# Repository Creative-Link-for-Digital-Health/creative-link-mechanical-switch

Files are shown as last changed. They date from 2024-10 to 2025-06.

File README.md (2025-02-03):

# Creative Link Mechanical Switch (CLMS)
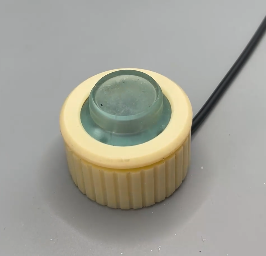
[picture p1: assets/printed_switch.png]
Printed
.
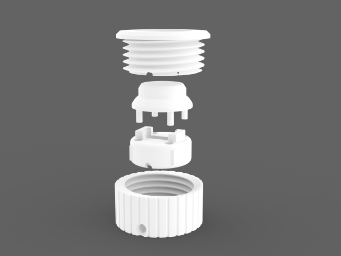
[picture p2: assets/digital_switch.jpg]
Digital
.
## Setup ##
*Hyperlink/Button to Youtube Tutorial*
1) Thread wire through hole of the 'mount'
2) Solder switch component to wire
3) Ensure switch component is flush with the top of the 'mount'
4) Firmly press the cord into the bottom inlaid portion of the 'mount'
5) Align the pegs of 'button' with the holes of the 'mount' *They will only perfectly fit in one orientation, if correct a click will be heard*
6) Align the pointed side pegs of the mount with the inside of the 'top screw'. Slide the 'button' and 'mount' through the bottom of the 'top screw' *Align the exit hole of the 'mount' and the 'top screw'*
7) Thread the end of the wire through the top of the 'bottom screw'. Screw together the 'top' and 'bottom' screw
## Citation
Use the following to cite Creative Link For Digital Health Two Part Switch:

- Smith H, Cooley Hidecker M J, Kitzman P,
  **Creative Link**, 2024-,
  https://github.com/Creative-Link-for-Digital-Health/two-part-switch/ [Online; accessed ```<year>-<month>-<day>```].

```latex
@Misc{,
  author = {Hannah Smith and Mary Jo Cooley Hidecker and Patrick Kitzman},
  title = {Creative Link for Digital Health: Mechanical Switch},
  year = {2024--},
  url = "https://github.com/Creative-Link-for-Digital-Health/two-part-switch/",
  note = {[Online; accessed <today>]}
}
```
This project was developed with support from the [University of Kentucky Office of the Vice President for Research](https://www.research.uky.edu/vice-president-research) Emerging Themes for Research Program – [Creative Link for Advancing Digital Health](https://creative.ai.uky.edu/).

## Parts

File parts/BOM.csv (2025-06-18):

Bill of Materials
Item: | Amount: | Source: | Link:
Tactile Tact Push Button | 1 | Octopart | https://octopart.com/search?q=SS-3GP
Open End TRS | 1 | Amazon | https://www.amazon.com/Fancasee-Replacement-Connector-Headphone-Earphone/dp/B082VVWND3
Switch_Bottom_Screw | 1 | Print | https://github.com/Creative-Link-for-Digital-Health/creative-link-mechanical-switch/tree/main/parts
Switch_Top_Screw | 1 | Print | https://github.com/Creative-Link-for-Digital-Health/creative-link-mechanical-switch/tree/main/parts
Switch_Button | 1 | Print | https://github.com/Creative-Link-for-Digital-Health/creative-link-mechanical-switch/tree/main/parts
Switch_Mount | 1 | Print | https://github.com/Creative-Link-for-Digital-Health/creative-link-mechanical-switch/tree/main/parts

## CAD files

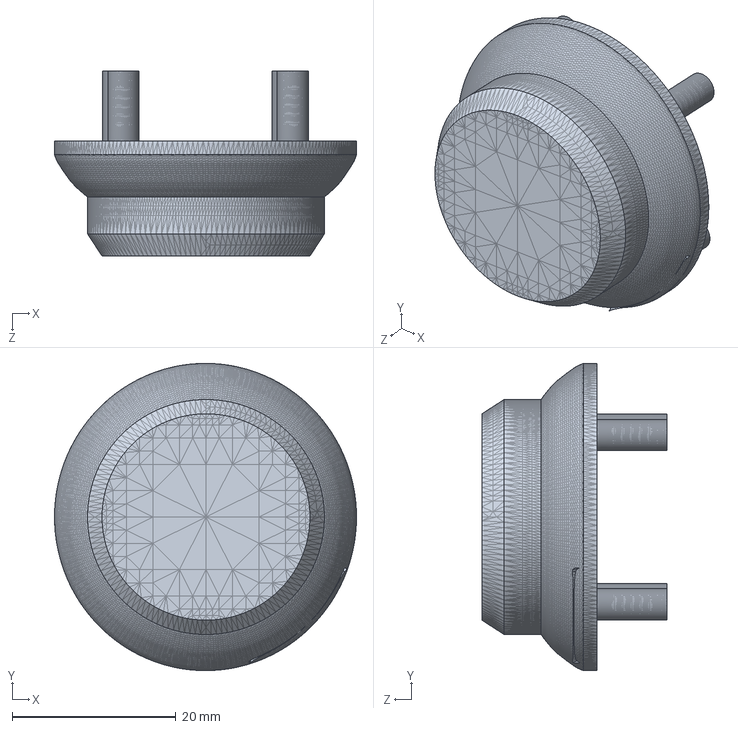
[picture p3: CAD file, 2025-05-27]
parts/switch_button_v1_sla_final_solidworks.SLDPRT
36.9 x 37.5 x 22.6 mm

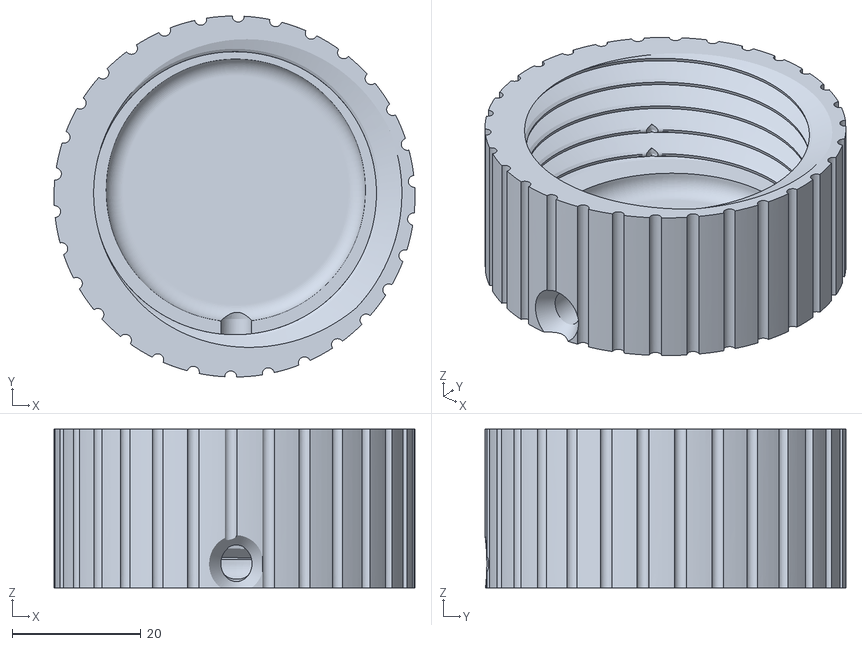
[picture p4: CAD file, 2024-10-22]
parts/switch_bottom_screw_v1_sla_final.stl
56.1 x 56.1 x 24.7

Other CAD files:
parts/switch_button_v1_sla_final.stl

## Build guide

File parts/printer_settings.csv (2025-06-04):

Parameters | Values
Material | PLA
Layer Height | 0.20
Infill Percentage | 20
Infill Pattern | Gyroid

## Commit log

2024-11-05 moved BOM
    [BOM.csv]
2024-11-10 Rename switch bottom screw_V1_sla_final.stl to switch_bottom_screw_V1_sla_final.stl
    [switch bottom screw_V1_sla_final.stl, switch_bottom_screw_V1_sla_final.stl]
2024-11-10 Rename switch_bottom screw_V1_sla_final.stl to switch_bottom_screw_v1_sla_final.stl
    [switch_bottom screw_V1_sla_final.stl, switch_bottom_screw_v1_sla_final.stl]
2025-05-27 Adding solidworks files for CLMS
    [switch_button_v1_sla_final_solidworks.SLDPRT]
